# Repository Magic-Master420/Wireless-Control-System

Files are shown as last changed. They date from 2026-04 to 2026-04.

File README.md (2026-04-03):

# Wireless Control System

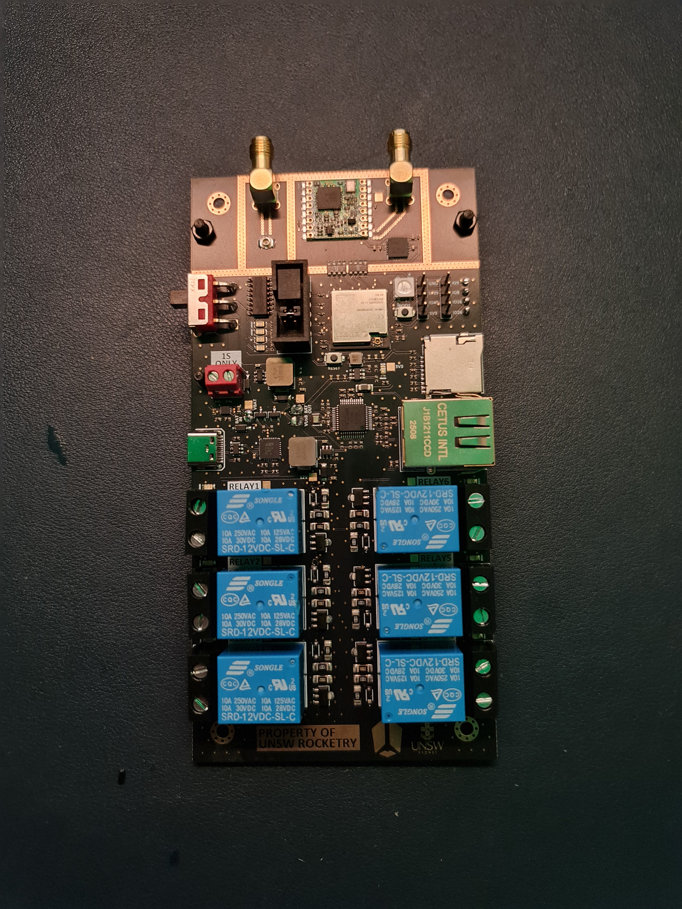
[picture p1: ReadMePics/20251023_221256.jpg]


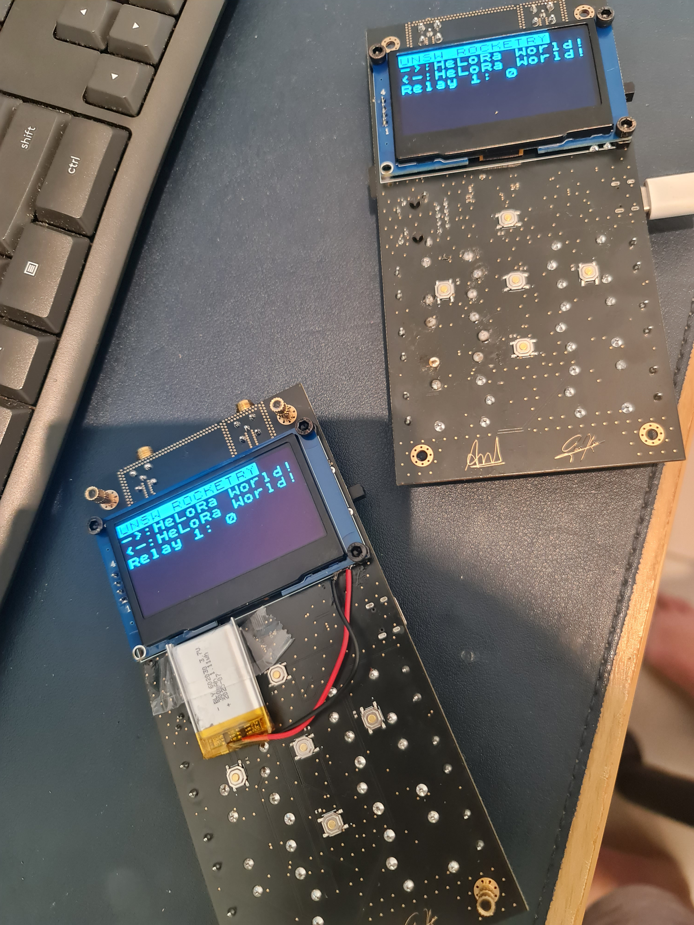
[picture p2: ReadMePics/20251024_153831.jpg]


## Overview
This project was tasked by UNSW rocketry's propulsions sub-team to design a wireless module which is used to launch a two stage rocket over a 800m distance and retrieve sensor data.

The module is powered by an ESP32-S3-MINI-U1 which features a dual core processor, where each processor can be used for a dedicated function. For wireless communication, it is done over LoRa. An off-the-shelf module is utilized in this design. Other features includes an OLED display for viewing information, battery charging system to make the device modular, relays for high voltage/current control, and ethernet for high bandwidth wired communication.

## Known issues
- The wireless charging IC needs two pull up resistors on the battery status indicator pins to correctly display battery state. The pins are open drain which is mentioned in the datasheet but I didn't realize I needed them. Update your schematics accordingly.
- The zener diode implemented on the relay-controls schematic has a breakdown voltage of 4.7V while the anode voltage is 12V and the cathode is about 0V. This caused the supply voltage to constantly be clamped to 4.7V which hinders the functionality of the relays. Remove the zener diode or use a diode with a higher breakdown voltage in your design.

## Notes
- Relays utilized can be connected to mains voltage for high power control. See BOM for part number and search the datasheet for more details on the part.
- The design includes male breakout headers pins for unused pin connections on the ESP32, you can connect external devices to these pins for control. The header pins also include an I2C bus.
- The code is written such that the data is transmitted without checking whether or not it has successfully been received on the other end. The transport layer needs to be improved to ensure reliable communication. Here are some recommended transport layer protocols:
  - Stop-And-Wait:     low throughput, low memory
  - Go-Back-N:         High throughput, low memory
  - Selective-Repeat:  High throughput, high memory

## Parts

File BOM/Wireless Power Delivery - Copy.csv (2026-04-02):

Line # | Name | Description | Designator | Revision ID | Revision Status | Quantity | Manufacturer 1 | Manufacturer Part Number 1 | Manufacturer Lifecycle 1 | Supplier 1 | Supplier Part Number 1 | Supplier Unit Price 1 | Supplier Subtotal 1
 | CL05B104KB54PNC | Capacitor SMD 0402 | C1, C2, C5, C10, C12, C14, C15, C18, C19, C21, C28, C29, C30, C31, C32, C33, C34 |  |  | 17
 | CL05A106MQ5NUNC | Capacitor SMD 0402 | C3, C4, C9, C11, C13, C16, C17, C20, C22, C27, C35 |  |  | 11
 | GRM158R61A226ME15D | Capacitor SMD 0402 | C6, C7, C8, C23, C24, C25, C26 |  |  | 7
 | 0402B223K500NT | Capacitor SMD 0402 | C36 |  |  | 1
 | 0402CG8R0C500NT | Capacitor SMD 0402 | C37, C39 |  |  | 2
 | 0402B682K500NT | Capacitor SMD 0402 | C38, C40 |  |  | 2
 | CL05B103KB5NNNC | Capacitor SMD 0402 | C41, C43 |  |  | 2
 | CL05A475MP5NRNC | Capacitor SMD 0402 | C42 |  |  | 1
 | CC0402KRX7R0BB102 | Capacitor SMD 0402 100V | C44 |  |  | 1
 | TF PUSH |  | CARD1 |  |  | 1
 | USBLC6-2SC6 |  | D1 |  |  | 1
 | 1N5819HW-7-F | DIODE SCHOTTKY 40V 1A SOD123 | D2, D3 | CMP-0303-00003-3 | Up to date | 2 | Diodes Inc. | 1N5819HW-7-F | Volume Production | Avnet | 51R7874 | 0.312 | 0.624
 | LTST-C170KFKT | LED ORANGE CLEAR SMD | D5 | CMP-22017-000036-1 | Up to date | 1 | Lite-On | LTST-C170KFKT | Volume Production | DigiKey | 160-1413-1-ND | 0.13 | 0.13
 | SS34LWHRVG | DIODE SCHOTTKY 40V 3A SOD123W | D6, D9 | CMP-15604-000001-1 | Up to date | 2 | Taiwan Semiconductor | SS34LWHRVG | Volume Production
 | LTST-C170KRKT | LED Red, 75 mW, 54 mcd, -55 to 85 degC, 2-Pin SMD, RoHS, Tape and Reel | DS1, DS2, DS3, DS4, DS5, DS6, DS7, DS8, DS9 | CMP-2000-07593-1 | Up to date | 9 | Lite-On | LTST-C170KRKT | Volume Production | Mouser | 859-LTST-C170KRKT | 0.111 | 1.11
 | LTST-C170KGKT | Ultra Bright AlInGaP Chip LED, 75 mW, -55 to 85 degC, 2-Pin SMD (0805), RoHS, Tape and Reel | DS10 | CMP-2000-06620-1 | Up to date | 1 | Lite-On | LTST-C170KGKT | Volume Production | DigiKey | 160-1414-1-ND | 0.14 | 0.14
 | BLM31PG121SN1L | Chip Ferrite Bead Array, 1206, 120O @ 100MHz, 0.02O, 25%, 3.5A | FB1 | CMP-0686-00732-3 | Up to date | 1 | Murata | BLM31PG121SN1L | Volume Production | DigiKey | 490-1056-1-ND | 0.3 | 0.3
 | BQ25185DLHR | Integrated Circuit | IC1 |  |  | 1
 | TYPE-C-31-M-12 | USB Type C Connector Horizontal SMT | J1 |  |  | 1
 | J1B1211CCD | CONN JACK 1PORT 100 BASE-T PCB | J2 | CMP-240752-000001-1 | Up to date | 1 | WIZnet | J1B1211CCD | Unknown
 | 72454-010VLF | Connector | J3 |  |  | 1
 | U.FL-R-SMT-1(80) | CONN U.FL RCPT STR 50 OHM SMD | J6 | CMP-11598-000004-1 | Up to date | 1 | HIROSE ELECTRIC | U.FL-R-SMT-1(80) | Volume Production | DigiKey | 26-U.FL-R-SMT-1(80)CT-ND | 1.27 | 1.27
 | IHLP1212BZER2R2M11 | FIXED IND 2.2UH 3A 46 MOHM SMD | L1 | CMP-02424-000689-1 | Up to date | 1 | Vishay | IHLP1212BZER2R2M11 | Obsolete
 | IHLP2525EZER4R7M01 | Commercial Inductors, High Saturation Series 4.7uH 6.5A 30.3mO 20% | L2, L3 | CMP-02424-000065-1 | Up to date | 2 | Vishay | IHLP2525EZER4R7M01 | Volume Production | Farnell | IHLP2525EZER4R7M01 | 1.71 | 3.42
 | XL-5050RGBC-WS2812B |  | LED1 |  |  | 1
 | HS242L03B2C01 |  | OLED1 |  |  | 1
 | 61300411121 |  | P2, P3 | CMP-1502-01064-3 | Out of date | 2 | Wurth Elektronik | 61300411121 | Unknown | Mouser | 710-61300411121 | 0.19 | 0.38
 | D882(RANGE:160-320) |  | Q1, Q2, Q3, Q4, Q5, Q6 |  |  | 6
 | L8050QLT1G |  | Q7, Q8 |  |  | 2
 | RC1206FR-7W1KL | Resistor SMD 1206 1k 0.5W | R1, R12, R13, R14, R17, R18, R21, R22, R23, R24, R25, R26 |  |  | 12
 | 0402WGF5101TCE | Resistor SMD 0402 5.1k | R2, R3 |  |  | 2
 | 0402WGF1001TCE | Resistor SMD 0402 | R4, R8, R54, R55, R56, R57 |  |  | 6
 | 0402WGF1002TCE | Resistor SMD 0402 | R5, R7, R9, R16, R31, R33, R34, R35, R36, R37, R38, R39, R40, R41, R42, R44, R45, R46, R47, R48, R60, R61, R66, R67, R68 |  |  | 25
 | 0402WGF3322TCE | Resistor SMD 0402 | R6 |  |  | 1
 | 0402WGF2212TCE | Resistor SMD 0402 | R10 |  |  | 1
 | 0402WGF8202TCE | Resistor SMD 0402 | R11 |  |  | 1
 | 1206W4F1002T5E | Resistor SMD 1206 10k 0.25W | R15, R19, R20, R27, R28, R29 |  |  | 6
 | RC0402FR-074K3L | Resistor SMD 0402 | R30 |  |  | 1
 | RC0402FR-0747K5L | Resistor SMD 0402 | R32 |  |  | 1
 | 0603WAF1302T5E | Resistor SMD 0603 | R43 |  |  | 1
 | 0402WGF3000TCE | Resistor SMD 0402 | R49 |  |  | 1
 | CL0402FN604RP | Resistor SMD 0402 | R50 |  |  | 1
 | 0402WGF1201TCE | Resistor SMD 0402 | R51 |  |  | 1
 | FRC0402F3001TS | Resistor SMD 0402 | R52 |  |  | 1
 | RC0402FR-076K04L | Resistor SMD 0402 | R53 |  |  | 1
 | RC0402FR-07110KL | Resistor SMD 0402 | R58 |  |  | 1
 | 0402WGF1502TCE | Resistor SMD 0402 | R59 |  |  | 1
 | RT0402BRE0750RL | Resistor SMD 0402 | R62, R63, R70, R71 |  |  | 4
 | 0402WGF100JTCE | Resistor SMD 0402 | R64 |  |  | 1
 | 0402WGF1004TCE | Resistor SMD 0402 | R65 |  |  | 1
 | 0402WGF1242TCE | Resistor SMD 0402 | R69 |  |  | 1
 | 0402WGF3300TCE | Resistor SMD 0402 | R72, R73 |  |  | 2
 | 0402WGF330JTCE | Resistor SMD 0402 | R74, R75, R76, R77 |  |  | 4
 | SRD-12VDC-SL-C |  | RELAY1, RELAY2, RELAY3, RELAY4, RELAY5, RELAY6 |  |  | 6
 | BWSMA-KWE-Z001 |  | RF1, RF2 |  |  | 2
 | YC324-JK-070RL | Resistor Network | RN1, RN2 |  |  | 2
 | TS-1187A-B-A-B | Switch | S1, S2, S3, S4, S5 |  |  | 5
 | SS-12D11G5R | Switch | S6 |  |  | 1
 | SolderBridgeOpen | Close the brige with solder | SB1, SB2, SB3 |  |  | 3
 | TS-1088-AR02016 |  | SW1, SW2 |  |  | 2
 | ESP32-S3-MINI-1U-N8 | Bluetooth, WiFi 802.11b/g/n, Bluetooth v5.0 Transceiver Module 2.4GHz Antenna Not Included, U.FL Surface Mount | U1 |  |  | 1
 | TPS563200DDCR | IC REG BUCK ADJ 3A TSOT23-6 | U2 | CMP-04918-000155-1 | Up to date | 1 | Texas Instruments | TPS563200DDCR | Volume Production | Mouser | 595-TPS563200DDCR | 1.02 | 1.02
 | CP2102N-A02-GQFN28R | IC USB TO UART BRIDGE QFN28 | U3 | CMP-08093-000007-1 | Up to date | 1 | Silicon Lab | CP2102N-A02-GQFN28R | Volume Production | Mouser | 634-CP2102NA02QFN28R | 3.52 | 3.52
 | XY705V-7.5-2P |  | U4, U5, U6, U7, U8, U9 |  |  | 6
 | DB125-3.81-2P-RD-S |  | U10 |  |  | 1
 | MT3608L |  | U11, U15 |  |  | 2
 | TPS7A4700RGWR | IC REG LINEAR POS ADJ 1A 20VQFN | U12 | CMP-04917-000027-1 | Up to date | 1 | Texas Instruments | TPS7A4700RGWR | Volume Production
 | 915MHz |  | U13 |  |  | 1
 | SN74HC139DR | Dual 2-Line To 4-Line Decoders/Demultiplexers, D0016A, LARGE T&R | U14 | CMP-1633-00245-2 | Up to date | 1 | Texas Instruments | SN74HC139DR | Volume Production | Mouser | 595-SN74HC139DR | 0.46 | 0.46
 | W5500 | Hardwired TCP/IP embedded Ethernet controller | U16 |  |  | 1
 | XRCGB25M000F3A00R0 | CRYSTAL 25.0000MHZ 6PF SMD | Y1 | CMP-06054-000016-1 | Up to date | 1 | Murata | XRCGB25M000F3A00R0 | Volume Production | Newark | XRCGB25M000F3A00R0 | 0.509 | 0.509
 | BZT52C4V7 | Zener Diode | Z1, Z2, Z3, Z4, Z5, Z6 |  |  | 6

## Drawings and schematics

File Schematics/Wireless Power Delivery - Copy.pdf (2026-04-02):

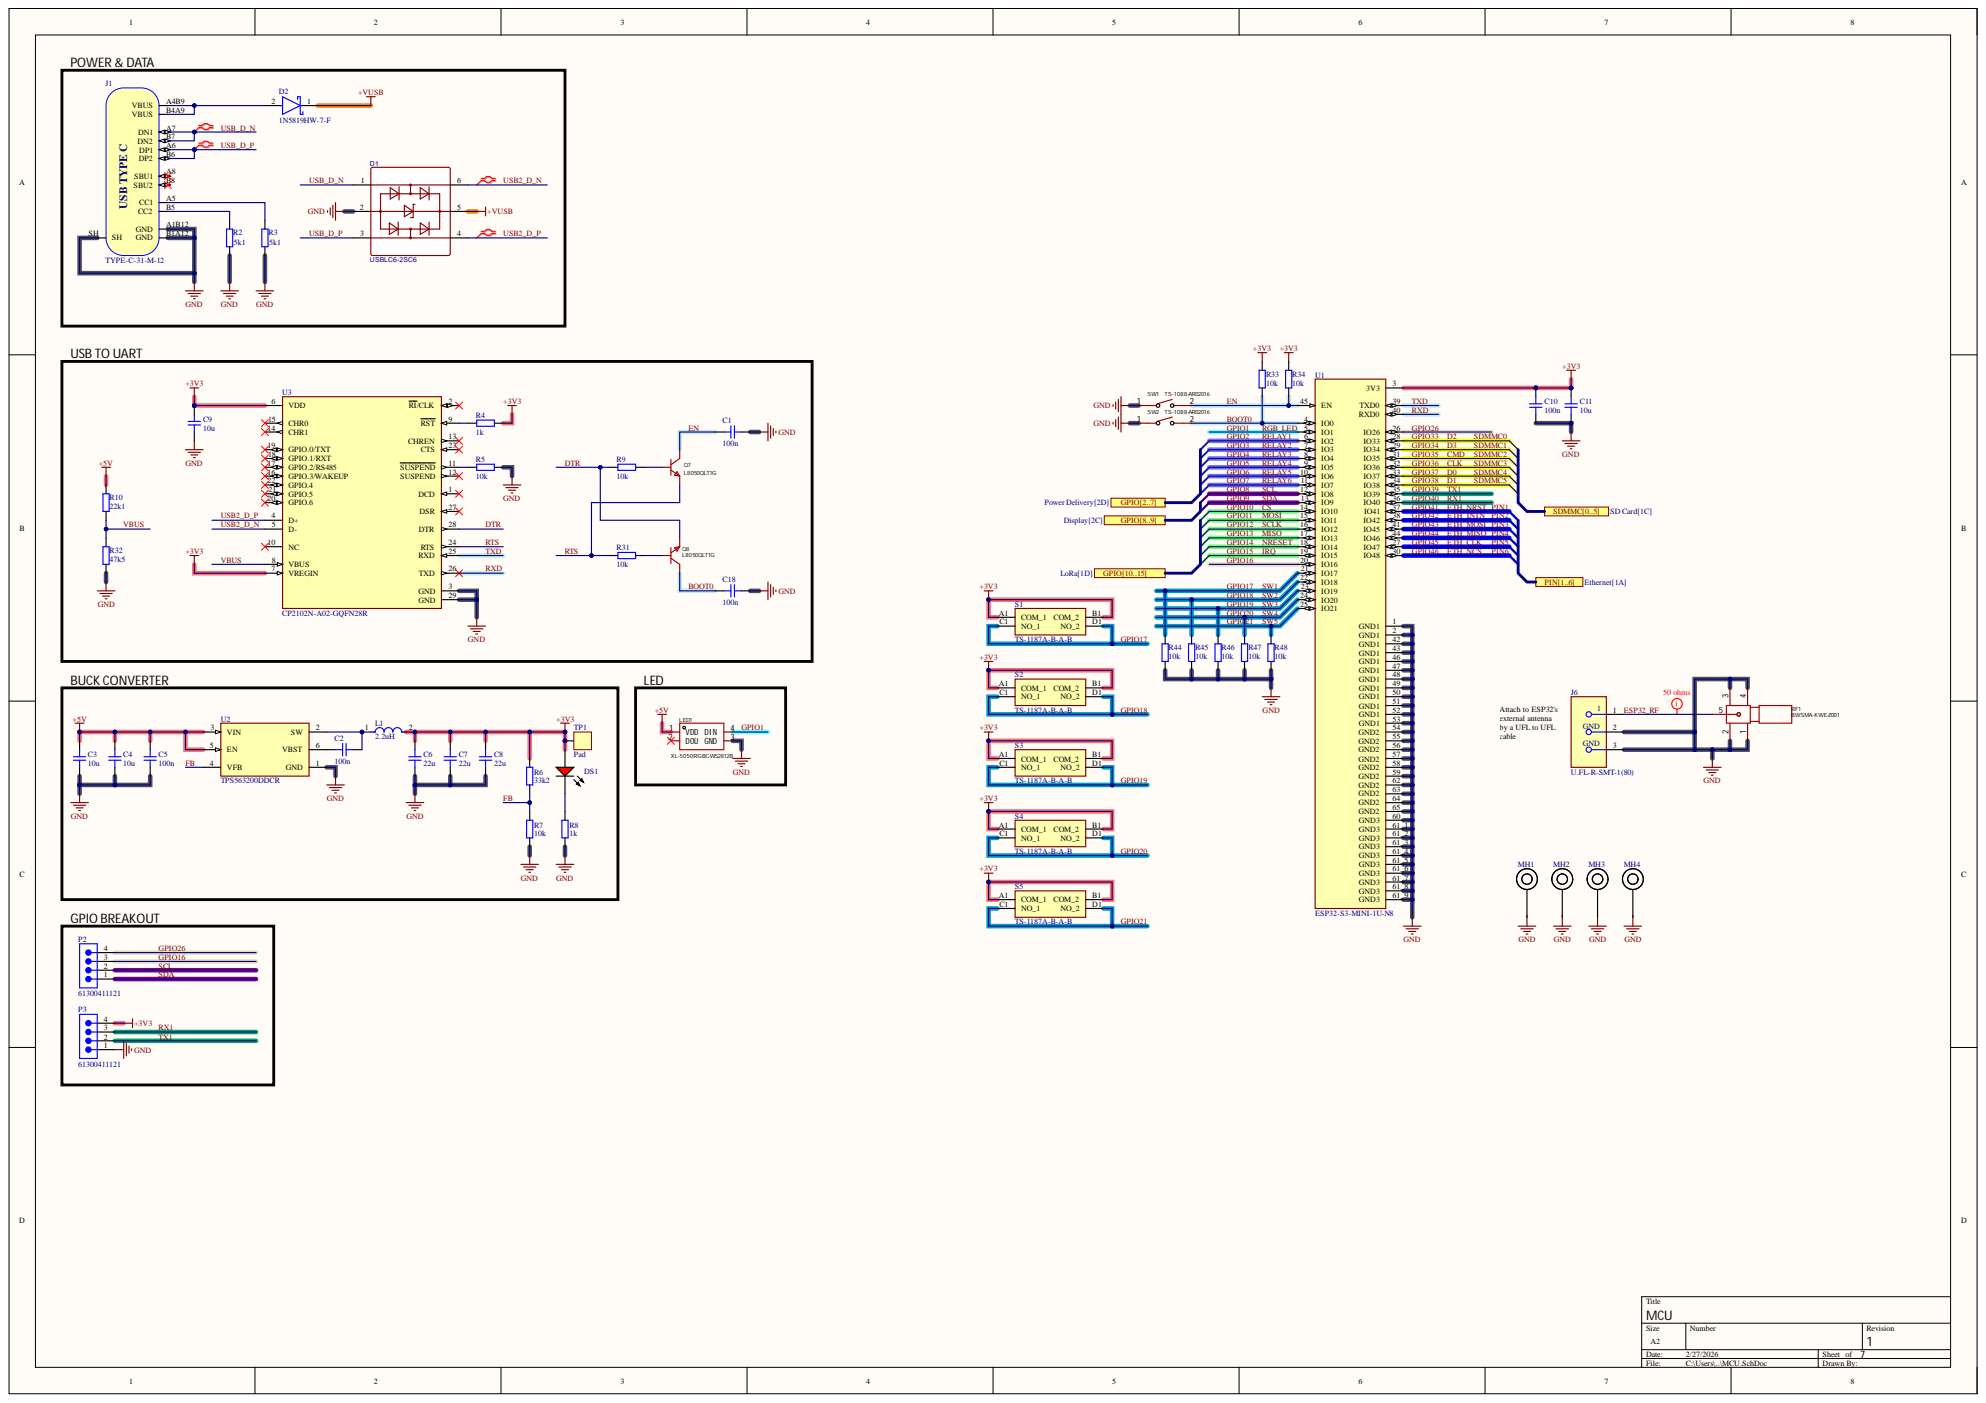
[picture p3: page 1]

Attach to ESP32's
external antenna
by a UFL to UFL
cable

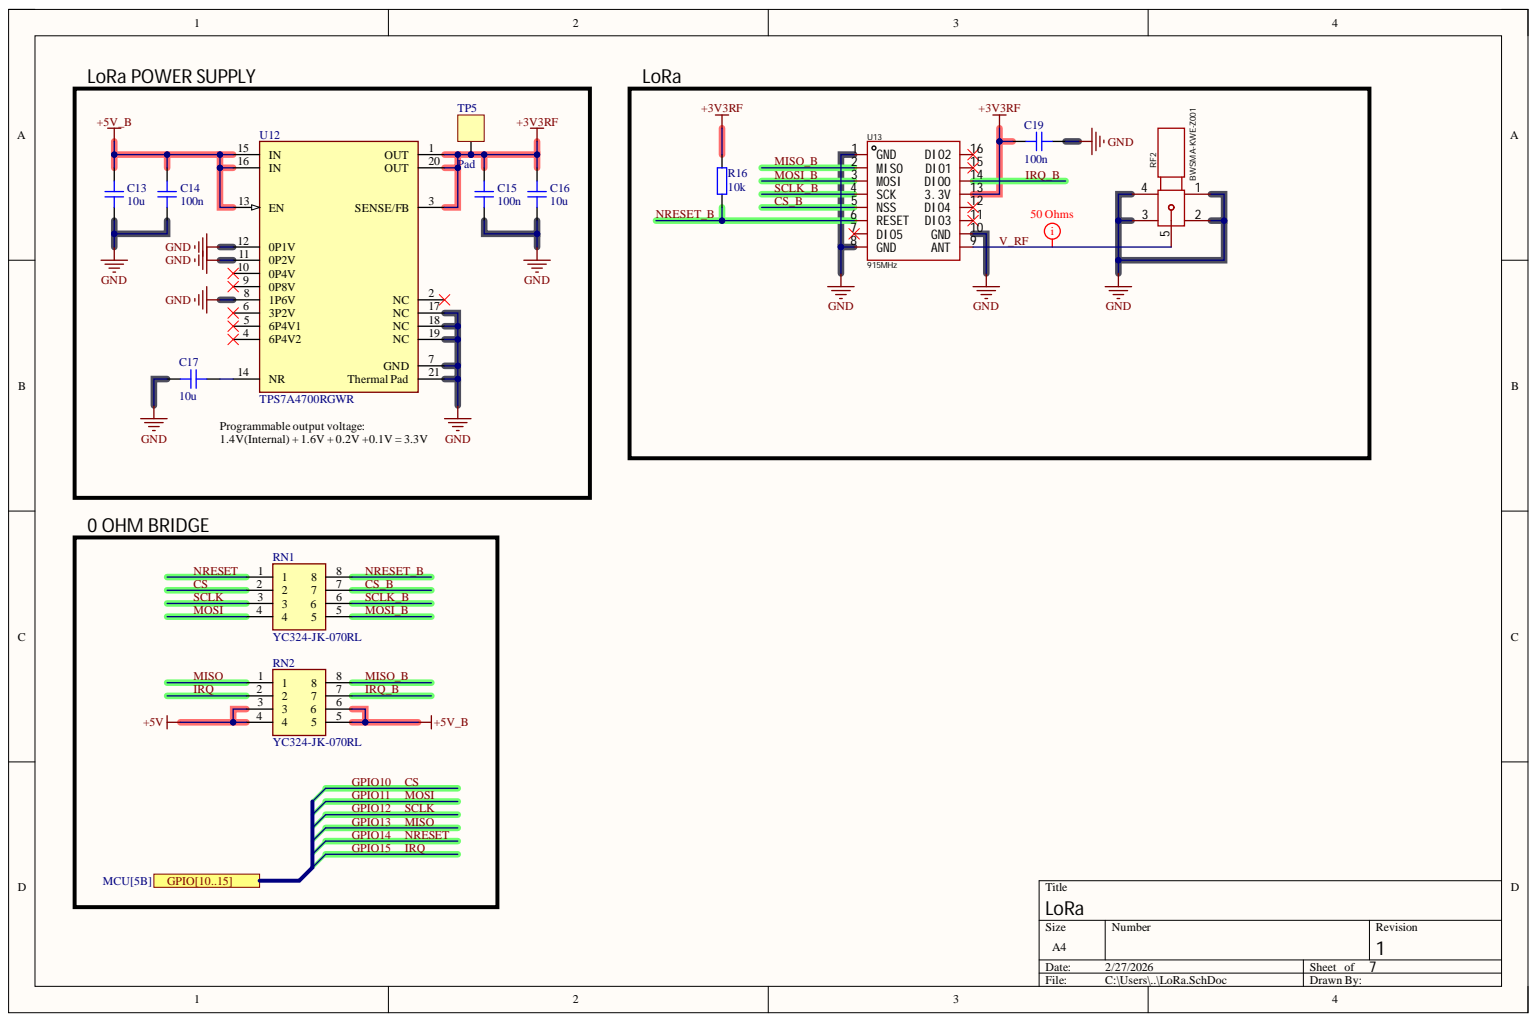
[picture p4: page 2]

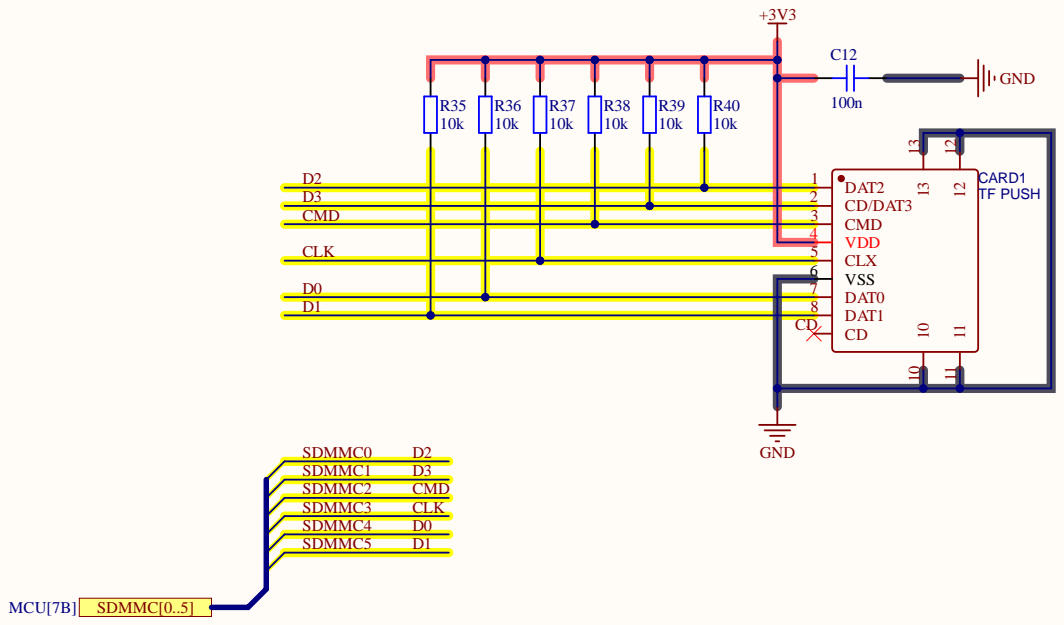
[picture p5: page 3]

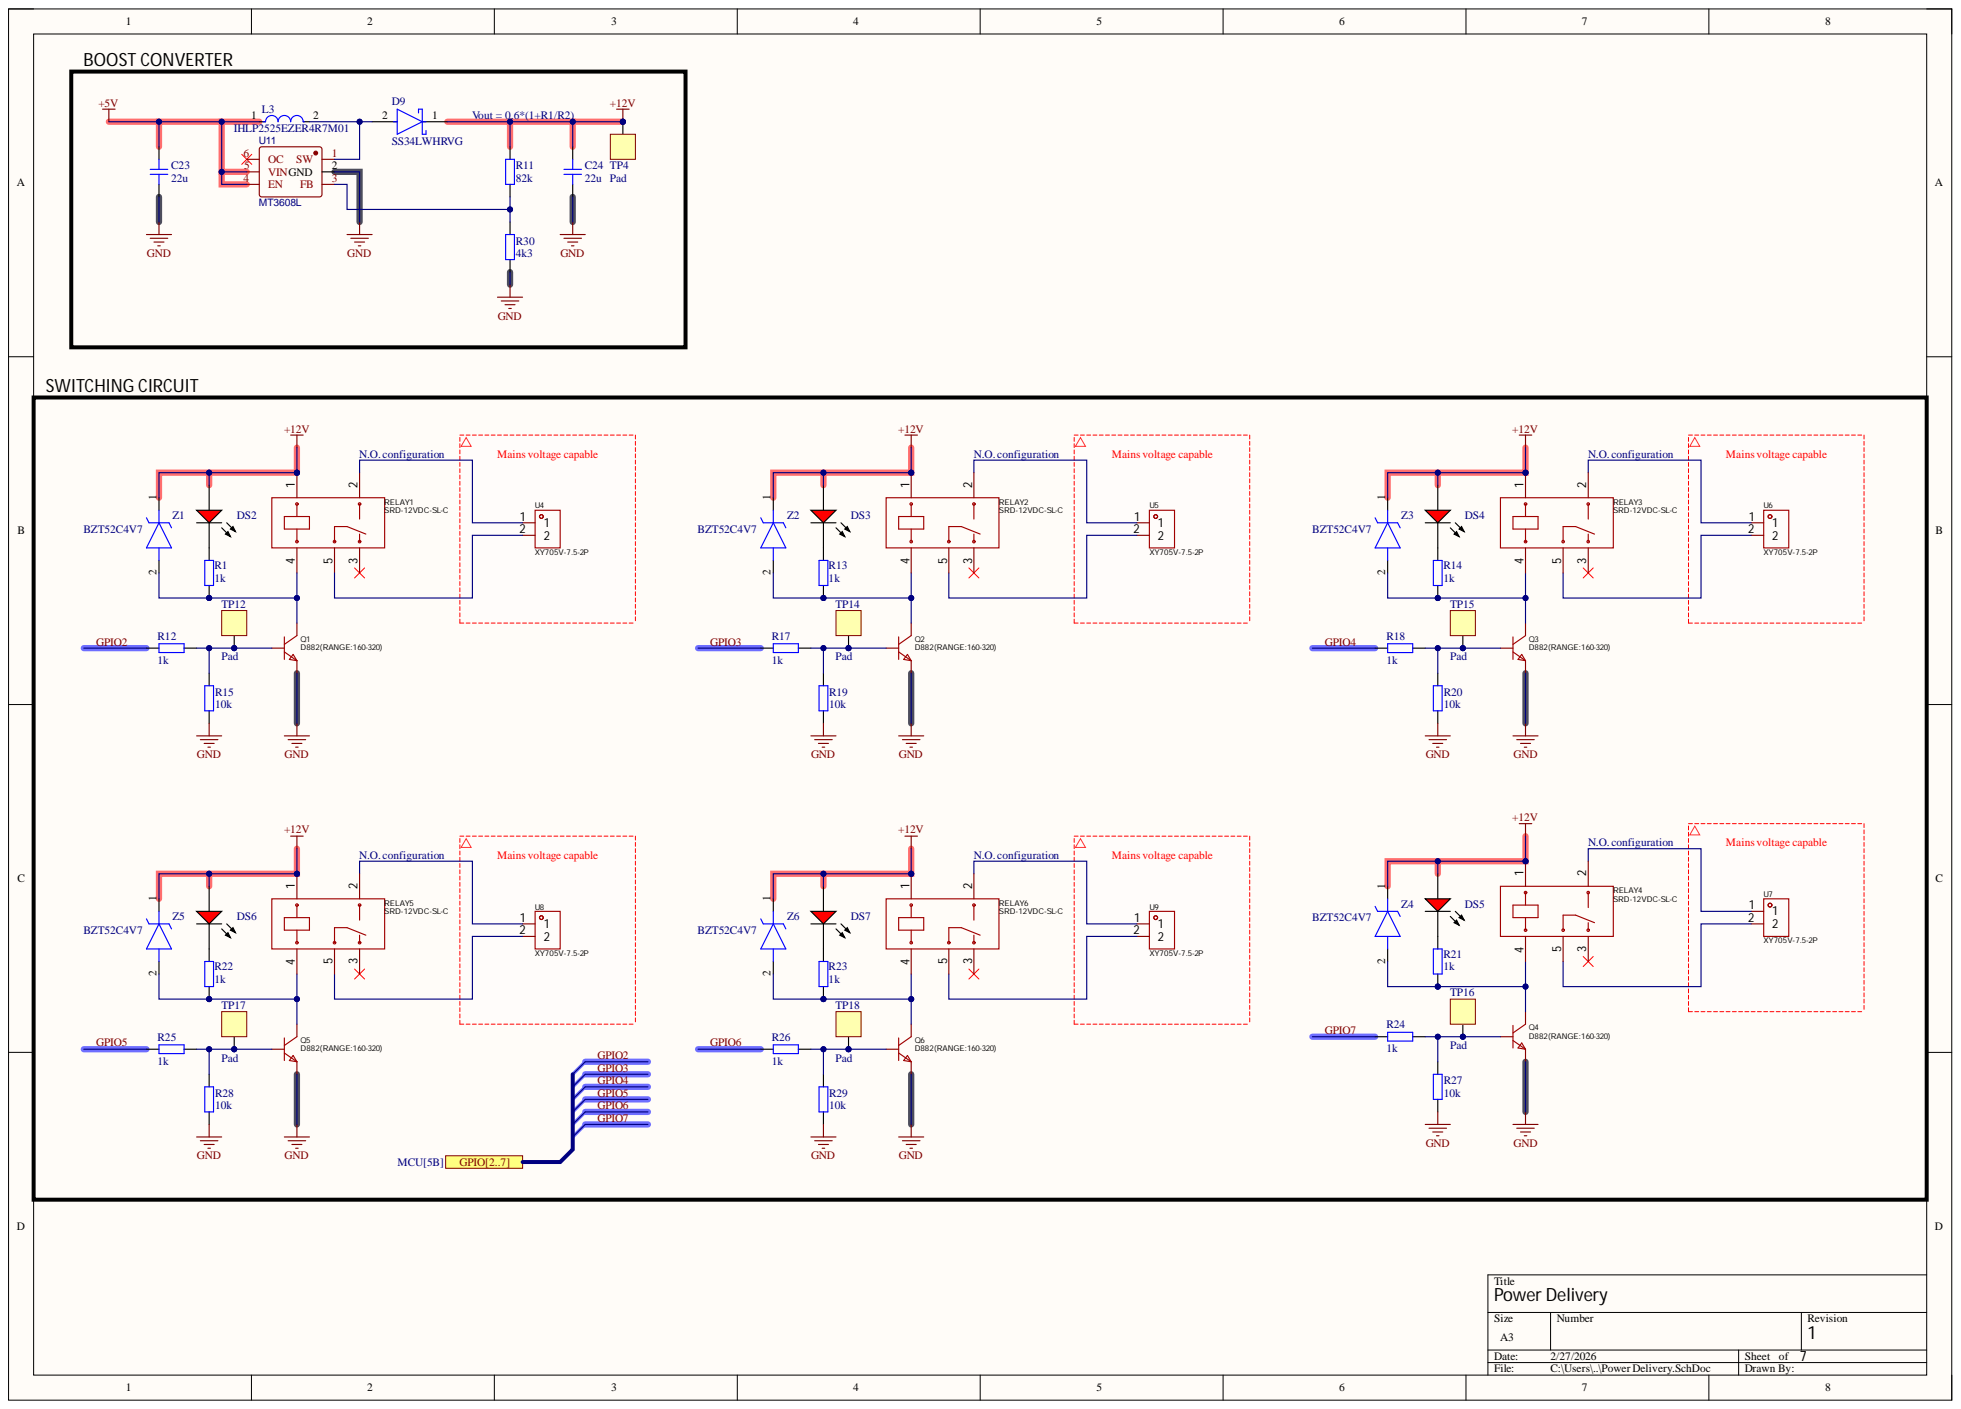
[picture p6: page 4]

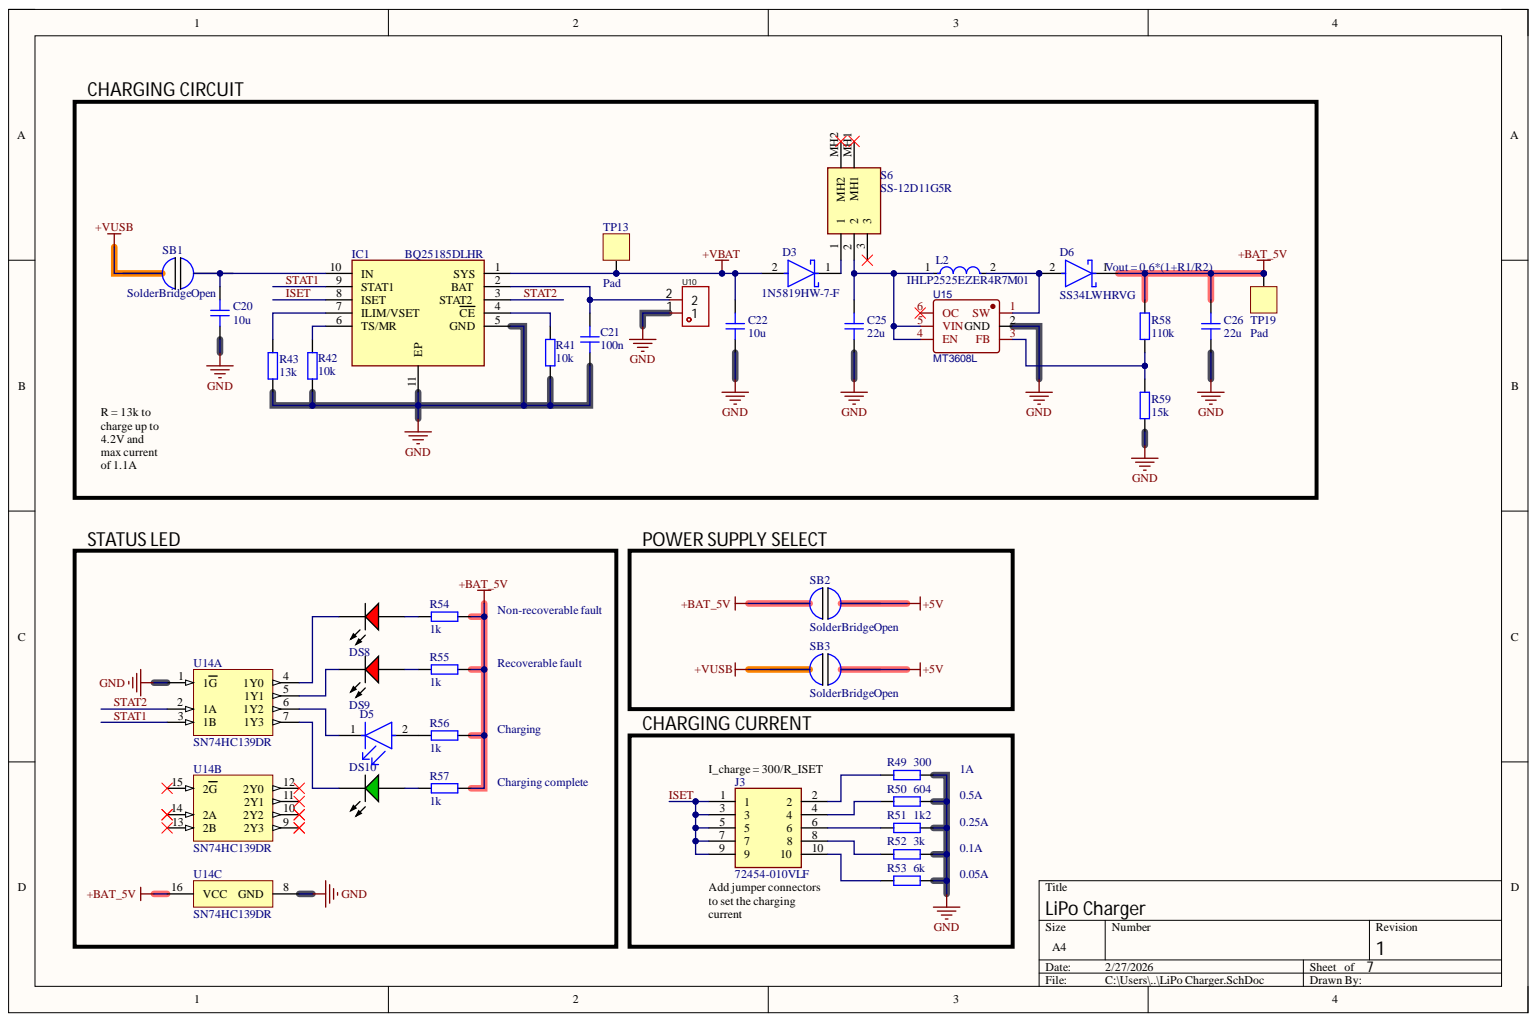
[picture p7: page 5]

72454-010VLF
Add jumper connectors
to set the charging
current

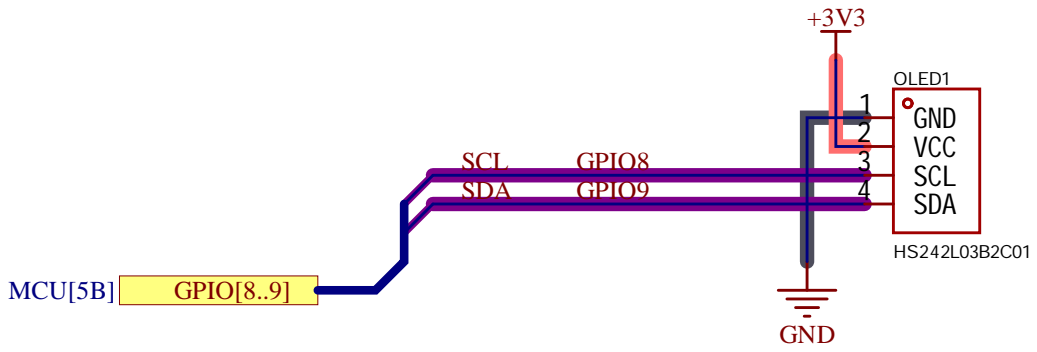
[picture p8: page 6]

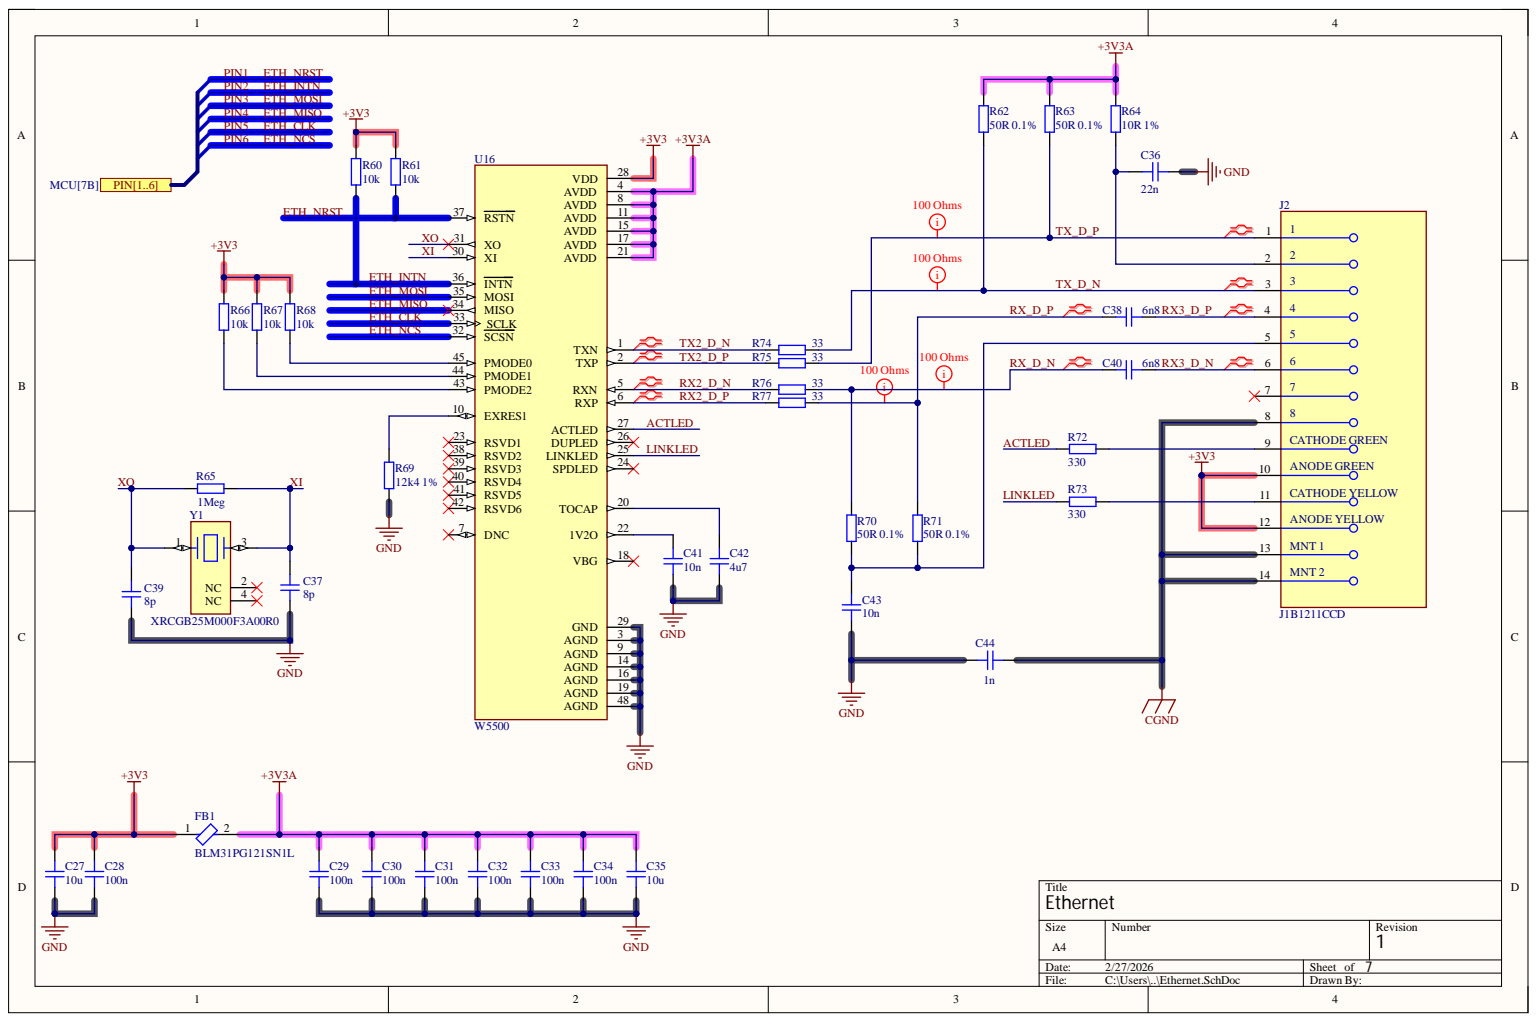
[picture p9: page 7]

100 Ohms | RX_D_N

EXRES1 10

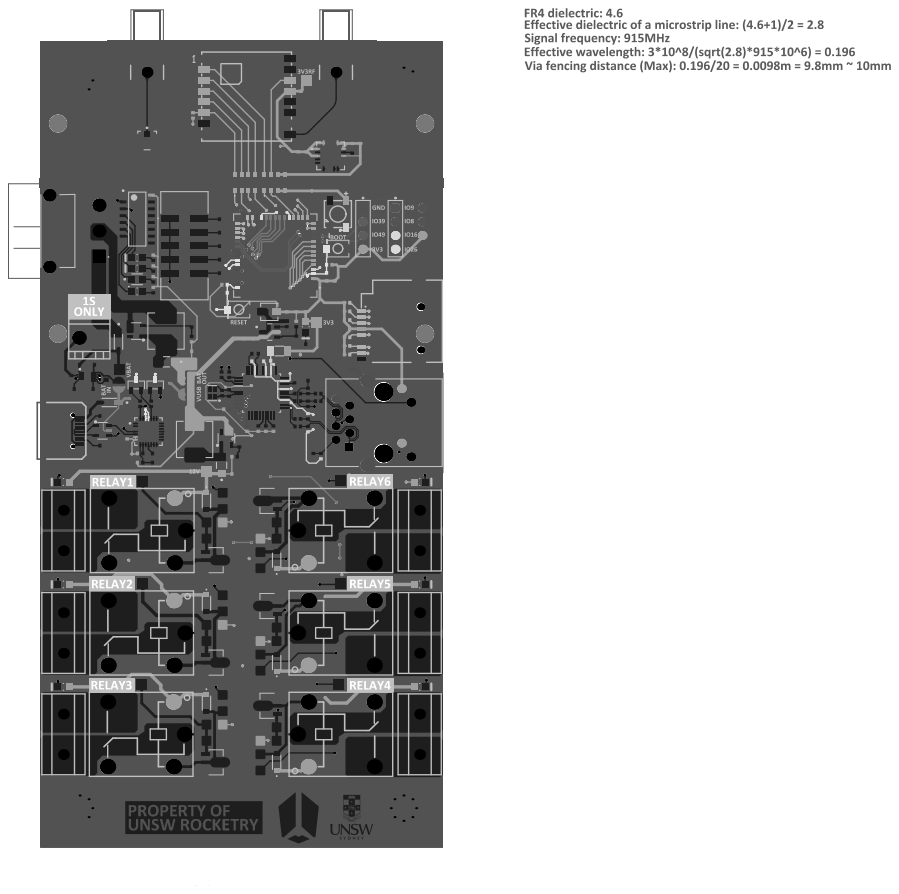
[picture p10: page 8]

Line# | Name | Description | Designator | Revision ID | Revision Status | Quantity | Manufacturer 1 | Manufacturer Part Number 1 | Manufacturer Lifecycle1 | Supplier 1 | Supplier Part Number 1 | Supplier Unit Price1 | Supplier Subtotal 1
CL05B104KB54PNC | Capacitor SMD

C1, C2, C5, C10,
C12, C14, C15,
C18, C19, C21,
C28, C29, C30,
C31, C32, C33, C34
CL05A106MQ5NUNC | Capacitor SMD | C3, C4, C9, C11, C13, C16, C17, C20, C22, C27, C35
GRM158R61A226ME15D | Capacitor SMD 0402 | C6, C7, C8, C23, C24, C25, C26 | | 7
0402B223K500NT | Capacitor SMD 0402 | C36 | | 1
0402CG8R0C500NT | Capacitor SMD 0402 | C37, C39 | | 2
0402B682K500NT | Capacitor SMD 0402 | C38, C40 | | 2
CL05B103KB5NNNC | Capacitor SMD 0402 | C41, C43 | | 2
CL05A475MP5NRNC | Capacitor SMD 0402 | C42 | | 1
CC0402KRX7R0BB102 | Capacitor SMD 0402100V | C44 | | 1
TFPUSH | | CARD1 | | 1
USBLC6-2SC6 | | D1 | | 1
1N5819HW-7-F | DIODESCHOTTKY 40V1ASOD123 | D2, D3 | | 2 Diodes Inc. | 1N5819HW-7-F | VolumeProduction
LTST-C170KFKT | LEDORANGE CLEARSMD | D5 | | 1 Lite-On | LTST-C170KFKT | VolumeProduction
SS34LWHRVG | DIODESCHOTTKY 40V3ASOD123W | D6, D9 | | 2 Taiwan Semiconductor | SS34LWHRVG | VolumeProduction
LTST-C170KRKT | LEDRed, 75mW, 54mcd, -55to 85 degC, 2-Pin SMD, RoHS, Tapeand Reel | DS1, DS2, DS3, DS4, DS5, DS6, DS7, DS8, DS9 | | 9 Lite-On | LTST-C170KRKT | VolumeProduction
LTST-C170KGKT | Ultra Bright AlInGaPChip LED, 75mW, -55to 85 degC, 2-Pin SMD (0805), RoHS, Tapeand Reel | DS10 | | 1 Lite-On | LTST-C170KGKT | VolumeProduction
BLM31PG121SN1L | Chip FerriteBead Array, 1206, 120Ω @100MHz, 0.02Ω, 25%, 3.5A | FB1 | | 1 Murata | BLM31PG121SN1L | VolumeProduction
BQ25185DLHR | Integrated Circuit | IC1 | | 1
TYPE-C-31-M-12 | USBTypeC Connector Horizontal SMT | J1 | | 1
J1B1211CCD | CONN JACK 1PORT100BASE-T PCB | J2 | | 1 WIZnet | J1B1211CCD
72454-010VLF | Connector | J3 | | 1
U.FL-R-SMT-1(80) | CONN U.FLRCPT STR50OHMSMD | J6 | | 1 HIROSEELECTRIC | U.FL-R-SMT-1(80) | VolumeProduction
IHLP1212BZER2R2M11 | FIXEDIND2.2UH 3A46MOHMSMD | L1 | | 1 Vishay | IHLP1212BZER2R2M11 | Obsolete
IHLP2525EZER4R7M01 | Commercial Inductors, High Saturation Series 4.7uH6.5A 30.3mΩ20% | L2, L3 | | 2 Vishay | IHLP2525EZER4R7M01 | VolumeProduction
XL-5050RGBC-WS2812B | | LED1 | | 1
HS242L03B2C01 | | OLED1 | | 1
61300411121 | | P2, P3 | | 2 Wurth Elektronik | 61300411121
D882(RANGE:160-320) | | Q1, Q2, Q3, Q4, Q5, Q6 | | 6
L8050QLT1G | | Q7, Q8 | | 2
RC1206FR-7W1KL | Resistor SMD1206 1k 0.5W | R1, R12, R13, R14, R17, R18, R21, R22, R23, R24, R25, R26 | 12
0402WGF5101TCE | Resistor SMD0402 5.1k | R2, R3 | | 2
0402WGF1001TCE | Resistor SMD0402 R4, R8, R54, R55, | R56, R57 | | 6
0402WGF1002TCE | Resistor SMD0402 | R5, R7, R9, R16, R31, R33, R34, R35, R36, R37, R38, R39, R40, R41, R42, R44, R45, R46, R47, R48, R60, R61, R66, R67, R68 | 25
0402WGF3322TCE | Resistor SMD0402 R6 | | | 1
0402WGF2212TCE | Resistor SMD0402 R10 | | | 1
0402WGF8202TCE | Resistor SMD0402 R11 | | | 1
1206W4F1002T5E | Resistor SMD1206 10k 0.25W | R15, R19, R20, R27, R28, R29 | | 6
RC0402FR-074K3L | Resistor SMD0402 R30 | | | 1
RC0402FR-0747K5L | Resistor SMD0402 R32 | | | 1
0603WAF1302T5E | Resistor SMD0603 R43 | | | 1
0402WGF3000TCE | Resistor SMD0402 R49 | | | 1
CL0402FN604RP | Resistor SMD0402 R50 | | | 1
0402WGF1201TCE | Resistor SMD0402 R51 | | | 1
FRC0402F3001TS | Resistor SMD0402 R52 | | | 1
RC0402FR-076K04L | Resistor SMD0402 R53 | | | 1
RC0402FR-07110KL | Resistor SMD0402 R58 | | | 1
0402WGF1502TCE | Resistor SMD0402 R59 | | | 1
RT0402BRE0750RL | Resistor SMD0402 R62, R63, R70, R71 | | | 4
0402WGF100JTCE | Resistor SMD0402 R64 | | | 1
0402WGF1004TCE | Resistor SMD0402 R65 | | | 1
0402WGF1242TCE | Resistor SMD0402 R69 | | | 1
0402WGF3300TCE | Resistor SMD0402 R72, R73 | | | 2
0402WGF330JTCE | Resistor SMD0402 R74, R75, R76, R77 | | | 4
SRD-12VDC-SL-C | | RELAY1, RELAY2, RELAY3, RELAY4, RELAY5, RELAY6 | | 6
BWSMA-KWE-Z001 | | RF1, RF2 | | 2
YC324-JK-070RL | Resistor Network | RN1, RN2 | | 2
TS-1187A-B-A-B | Switch | S1, S2, S3, S4, S5 | | 5
SS-12D11G5R | Switch | S6 | | 1
SolderBridgeOpen | Closethebrige with solder | SB1, SB2, SB3 | | 3
TS-1088-AR02016 | | SW1, SW2 | | 2
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

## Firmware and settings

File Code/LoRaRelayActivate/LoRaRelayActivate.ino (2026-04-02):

/*
  LoRa Duplex communication wth callback

  Sends a message every half second, and uses callback
  for new incoming messages. Implements a one-byte addressing scheme,
  with 0xFF as the broadcast address.

  Note: while sending, LoRa radio is not listening for incoming messages.
  Note2: when using the callback method, you can't use any of the Stream
  functions that rely on the timeout, such as readString, parseInt(), etc.

  created 28 April 2017
  by Tom Igoe
*/
#include <SPI.h>              // include libraries
#include <LoRa.h>
#include <Arduino.h>
#include <U8x8lib.h>
#include <Wire.h>

#ifdef U8X8_HAVE_HW_SPI
#endif

#ifdef ARDUINO_SAMD_MKRWAN1300
#error "This example is not compatible with the Arduino MKR WAN 1300 board!"
#endif

const int csPin = 10;          // LoRa radio chip select
const int resetPin = 14;       // LoRa radio reset
const int irqPin = 15;         // change for your board; must be a hardware interrupt pin
int pushButtonMiddlePin = 17;
volatile bool isPushButtonPressed = false;
int relay1Pin = 2;
int relay1State = 0;
int lastInterruptTime = 0;
char timeString[16];

String message = "HeLoRa World!";   // send a message
String recievedMessage = "";
String toggleRelayMiddle = "Toggle relay";
String sendMyMessage = "";

String outgoing;              // outgoing message
byte msgCount = 0;            // count of outgoing messages
byte localAddress = 0xBB;     // address of this device
byte destination = 0xFF;      // destination to send to
int lastSendTime = 0;        // last send time
int lastRecievedTime = 0;    // last recieved time
int interval = 2000;          // interval between sends

U8X8_SSD1306_128X64_NONAME_HW_I2C u8x8(U8X8_PIN_NONE);

void setup() {
  Serial.begin(115200);                   // initialize serial

  while (!Serial);

  // ********** LoRa setup **********
  Serial.println("LoRa Duplex with callback");
  //SPI.begin(SCK, MISO, MOSI, SS);
  SPI.begin(12, 13, 11, 10);  
  // override the default CS, reset, and IRQ pins (optional)
  LoRa.setPins(csPin, resetPin, irqPin);// set CS, reset, IRQ pin
  if (!LoRa.begin(915E6)) {             // initialize ratio at 915 MHz
    Serial.println("LoRa init failed. Check your connections.");
    while (true);                       // if failed, do nothing
  }
  LoRa.onReceive(onReceive);
  LoRa.receive();
  Serial.println("LoRa init succeeded.");
  // ********** LoRa setup **********
  
  // ********** Button and relay setup **********
  attachInterrupt(digitalPinToInterrupt(pushButtonMiddlePin), pushButtonISR, RISING);
  pinMode(relay1Pin, OUTPUT);
  digitalWrite(relay1Pin, LOW);
  // ********** Button and relay setup **********

  // ********** Display setup **********
  Wire.begin(9, 8);    // Set custom SDA and SCL pins
  u8x8.begin();
  u8x8.setPowerSave(0);
  u8x8.setFont(u8x8_font_chroma48medium8_r);
  u8x8.setInverseFont(1);
  u8x8.drawString(0,0," UNSW ROCKETRY ");
  u8x8.setInverseFont(0);
  // ********** Display setup **********
}

void loop() {
  if (millis() - lastSendTime > interval) {
    if(isPushButtonPressed){
      sendMessage(toggleRelayMiddle);
      Serial.println("->:" + toggleRelayMiddle);
      sendMyMessage = "->:" + toggleRelayMiddle;
      u8x8.drawString(0,1,"->:             ");
      u8x8.drawString(0,1,sendMyMessage.c_str());
      isPushButtonPressed = false;
    } else{
      sendMessage(message);
      Serial.println("->:" + message);
      sendMyMessage = "->:" + message;
      u8x8.drawString(0,1,"->:             ");
      u8x8.drawString(0,1,sendMyMessage.c_str());
    }
    
    sprintf(timeString, "%d", (millis() - lastSendTime));
    sendMyMessage = "Last sent:" + String(timeString);
    u8x8.drawString(0,2,"Last sent:      ");
    u8x8.drawString(0,2,sendMyMessage.c_str());
    lastSendTime = millis();            // timestamp the message
    interval = 250;//random(2000) + 1000;     // 2-3 seconds
    LoRa.receive();                     // go back into receive mode
    if(recievedMessage == toggleRelayMiddle){
      (relay1State == 1) ? relay1State = 0 : relay1State = 1;
      digitalWrite(relay1Pin, relay1State);
      message = "HeLoRa World!"; // reset back to HeLoRa World to prevent constant change
    }
  }

  sendMyMessage = "<-:" + recievedMessage;
  u8x8.drawString(0,3,"<-:             ");
  u8x8.drawString(0,3,sendMyMessage.c_str());
  sprintf(timeString, "%d", (millis() - lastRecievedTime));
  sendMyMessage = "Last rcvd:" + String(timeString);
  u8x8.drawString(0,4,"Last rcvd:      ");
  u8x8.drawString(0,4,sendMyMessage.c_str());

  sendMyMessage = "Relay 1: " + String(relay1State);
  u8x8.drawString(0,5,"Relay 1:        ");
  u8x8.drawString(0,5,sendMyMessage.c_str());
}

void pushButtonISR(){
  unsigned long currentTime = millis();
  if (currentTime - lastInterruptTime > 200) { // 200 ms debounce
    isPushButtonPressed = true;
    lastInterruptTime = currentTime;
  }
}

void sendMessage(String outgoing) {
  LoRa.beginPacket();                   // start packet
  LoRa.write(destination);              // add destination address
  LoRa.write(localAddress);             // add sender address
  LoRa.write(msgCount);                 // add message ID
  LoRa.write(outgoing.length());        // add payload length   
  LoRa.print(outgoing);                 // add payload
  LoRa.endPacket();                     // finish packet and send it
  msgCount++;                           // increment message ID
}

void onReceive(int packetSize) {
  if (packetSize == 0){
    u8x8.drawString(0,1,"Scanning...");
    return;          // if there's no packet, return
  }


  // read packet header bytes:
  int recipient = LoRa.read();          // recipient address
  byte sender = LoRa.read();            // sender address
  byte incomingMsgId = LoRa.read();     // incoming msg ID
  byte incomingLength = LoRa.read();    // incoming msg length

  String incoming = "";                 // payload of packet

  while (LoRa.available()) {            // can't use readString() in callback, so
    incoming += (char)LoRa.read();      // add bytes one by one
  }

  if (incomingLength != incoming.length()) {   // check length for error
    Serial.println("error: message length does not match length");
    return;                             // skip rest of function
  }

  // if the recipient isn't this device or broadcast,
  if (recipient != localAddress && recipient != 0xFF) {
    Serial.println("This message is not for me.");
    return;                             // skip rest of function
  }

  recievedMessage = incoming;
  // if message is for this device, or broadcast, print details:
  Serial.println("Received from: 0x" + String(sender, HEX));
  Serial.println("Sent to: 0x" + String(recipient, HEX));
  Serial.println("Message ID: " + String(incomingMsgId));
  Serial.println("Message length: " + String(incomingLength));
  Serial.println("Message: " + incoming);
  Serial.println("RSSI: " + String(LoRa.packetRssi()));
  Serial.println("Snr: " + String(LoRa.packetSnr()));
  Serial.println();
  lastRecievedTime = millis();
}

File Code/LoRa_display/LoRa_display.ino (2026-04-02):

/*

  HelloWorld.ino
  
  "Hello World" version for U8x8 API

  Universal 8bit Graphics Library (https://github.com/olikraus/u8g2/)

  Copyright (c) 2016, olikraus@gmail.com
  All rights reserved.

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
  THIS SOFTWARE IS PROVIDED BY THE COPYRIGHT HOLDERS AND 
  CONTRIBUTORS "AS IS" AND ANY EXPRESS OR IMPLIED WARRANTIES, 
  INCLUDING, BUT NOT LIMITED TO, THE IMPLIED WARRANTIES OF 
  MERCHANTABILITY AND FITNESS FOR A PARTICULAR PURPOSE ARE 
  DISCLAIMED. IN NO EVENT SHALL THE COPYRIGHT HOLDER OR 
  CONTRIBUTORS BE LIABLE FOR ANY DIRECT, INDIRECT, INCIDENTAL, 
  SPECIAL, EXEMPLARY, OR CONSEQUENTIAL DAMAGES (INCLUDING, BUT 
  NOT LIMITED TO, PROCUREMENT OF SUBSTITUTE GOODS OR SERVICES; 
  LOSS OF USE, DATA, OR PROFITS; OR BUSINESS INTERRUPTION) HOWEVER 
  CAUSED AND ON ANY THEORY OF LIABILITY, WHETHER IN CONTRACT, 
  STRICT LIABILITY, OR TORT (INCLUDING NEGLIGENCE OR OTHERWISE) 
  ARISING IN ANY WAY OUT OF THE USE OF THIS SOFTWARE, EVEN IF 
  ADVISED OF THE POSSIBILITY OF SUCH DAMAGE.  

*/

#include <Arduino.h>
#include <U8x8lib.h>
#include <Wire.h>

#ifdef U8X8_HAVE_HW_SPI
#include <SPI.h>
#endif

// Please UNCOMMENT one of the contructor lines below
// U8x8 Contructor List 
// The complete list is available here: https://github.com/olikraus/u8g2/wiki/u8x8setupcpp
// Please update the pin numbers according to your setup. Use U8X8_PIN_NONE if the reset pin is not connected
//U8X8_NULL u8x8;	// null device, a 8x8 pixel display which does nothing
//U8X8_SSD1306_128X64_NONAME_4W_SW_SPI u8x8(/* clock=*/ 13, /* data=*/ 11, /* cs=*/ 10, /* dc=*/ 9, /* reset=*/ 8);
//U8X8_SSD1306_128X64_NONAME_4W_HW_SPI u8x8(/* cs=*/ 6, /* dc=*/ 4, /* reset=*/ 12);	// Arduboy (DevKit)
//U8X8_SSD1306_128X64_NONAME_4W_HW_SPI u8x8(/* cs=*/ 12, /* dc=*/ 4, /* reset=*/ 6);	// Arduboy 10 (Production, Kickstarter Edition)
//U8X8_SSD1306_128X64_NONAME_4W_HW_SPI u8x8(/* cs=*/ 10, /* dc=*/ 9, /* reset=*/ 8);
//U8X8_SSD1306_128X64_NONAME_3W_SW_SPI u8x8(/* clock=*/ 13, /* data=*/ 11, /* cs=*/ 10, /* reset=*/ 8);
//U8X8_SSD1306_128X64_NONAME_3W_HW_SPI u8x8(/* cs=*/ 10, /* reset=*/ 8);
//U8X8_SSD1306_128X64_NONAME_HW_I2C u8x8(/* reset=*/ U8X8_PIN_NONE); 	      
//U8X8_SSD1306_128X64_ALT0_HW_I2C u8x8(/* reset=*/ U8X8_PIN_NONE); 	      // same as the NONAME variant, but may solve the "every 2nd line skipped" problem
//U8X8_SSD1306_128X64_NONAME_SW_I2C u8x8(/* clock=*/ 2, /* data=*/ 0, /* reset=*/ U8X8_PIN_NONE); 	      // Digispark ATTiny85
//U8X8_SSD1306_128X64_NONAME_SW_I2C u8x8(/* clock=*/ SCL, /* data=*/ SDA, /* reset=*/ U8X8_PIN_NONE);   // OLEDs without Reset of the Display
//U8X8_SSD1306_128X64_VCOMH0_4W_HW_SPI u8x8(/* cs=*/ 10, /* dc=*/ 9, /* reset=*/ 8);		// same as the NONAME variant, but maximizes setContrast() range
//U8X8_SSD1306_128X64_ALT0_4W_HW_SPI u8x8(/* cs=*/ 10, /* dc=*/ 9, /* reset=*/ 8);		// same as the NONAME variant, but may solve the "every 2nd line skipped" problem
//U8X8_SSD1306_102X64_EA_OLEDS102_4W_HW_SPI u8x8(/* cs=*/ 10, /* dc=*/ 9, /* reset=*/ 8);		// same as the NONAME variant, but may solve the "every 2nd line skipped" problem
//U8X8_SSD1312_128X64_NONAME_4W_SW_SPI u8x8(/* clock=*/ 13, /* data=*/ 11, /* cs=*/ 10, /* dc=*/ 9, /* reset=*/ 8);
//U8X8_SSD1312_128X64_NONAME_SW_I2C u8x8(/* clock=*/ SCL, /* data=*/ SDA, /* reset=*/ 8);
//U8X8_SSD1312_128X64_NONAME_HW_I2C u8x8(/* reset=*/ U8X8_PIN_NONE);
//U8X8_SSD1312_128X32_4W_SW_SPI u8x8(/* clock=*/ 13, /* data=*/ 11, /* cs=*/ 10, /* dc=*/ 9, /* reset=*/ 8);
//U8X8_SSD1312_128X32_SW_I2C u8x8(/* clock=*/ SCL, /* data=*/ SDA, /* reset=*/ 8);
//U8X8_SSD1312_128X32_HW_I2C u8x8(/* reset=*/ U8X8_PIN_NONE);
//U8X8_SSD1312_120X28_4W_SW_SPI u8x8(/* clock=*/ 13, /* data=*/ 11, /* cs=*/ 10, /* dc=*/ 9, /* reset=*/ 8);
//U8X8_SSD1312_120X28_SW_I2C u8x8(/* clock=*/ SCL, /* data=*/ SDA, /* reset=*/ 8);
//U8X8_SSD1312_120X28_HW_I2C u8x8(/* reset=*/ U8X8_PIN_NONE);
//U8X8_SH1106_128X64_NONAME_4W_HW_SPI u8x8(/* cs=*/ 10, /* dc=*/ 9, /* reset=*/ 8);
//U8X8_SH1106_128X64_NONAME_HW_I2C u8x8(/* reset=*/ U8X8_PIN_NONE);
//U8X8_SH1106_128X64_VCOMH0_4W_HW_SPI u8x8(/* cs=*/ 10, /* dc=*/ 9, /* reset=*/ 8);		// same as the NONAME variant, but maximizes setContrast() range
//U8X8_SH1106_128X64_WINSTAR_4W_HW_SPI u8x8(/* cs=*/ 10, /* dc=*/ 9, /* reset=*/ 8);		// same as the NONAME variant, but uses updated SH1106 init sequence
//U8X8_SH1106_128X32_VISIONOX_HW_I2C u8x8(/* reset=*/ U8X8_PIN_NONE); 
//U8X8_SH1106_128X32_VISIONOX_4W_HW_SPI u8x8(/* cs=*/ 10, /* dc=*/ 9, /* reset=*/ 8);
//U8X8_SH1106_72X40_WISE_4W_HW_SPI u8x8(/* cs=*/ 10, /* dc=*/ 9, /* reset=*/ 8);
//U8X8_SH1107_64X128_4W_HW_SPI u8x8(/* cs=*/ 10, /* dc=*/ 9, /* reset=*/ 8);
//U8X8_SH1107_128X128_4W_HW_SPI u8x8(/* cs=*/ 10, /* dc=*/ 9, /* reset=*/ 8);
//U8X8_SH1107_128X128_HW_I2C u8x8(/* reset=*/ 8);
//U8X8_SH1107_128X80_HW_I2C u8x8(/* reset=*/ 8);
//U8X8_SH1107_PIMORONI_128X128_HW_I2C u8x8(/* reset=*/ 8);
//U8X8_SH1107_SEEED_128X128_SW_I2C u8x8(/* clock=*/ SCL, /* data=*/ SDA, /* reset=*/ U8X8_PIN_NONE);
//U8X8_SH1107_SEEED_128X128_HW_I2C u8x8(/* reset=*/ U8X8_PIN_NONE);
//U8X8_SH1107_SEEED_96X96_4W_HW_SPI u8x8(/* cs=*/ 10, /* dc=*/ 9, /* reset=*/ 8);
//U8X8_SH1108_128X160_4W_HW_SPI u8x8(/* cs=*/ 10, /* dc=*/ 9, /* reset=*/ 8);
//U8X8_CH1120_128X160_4W_HW_SPI u8x8(/* cs=*/ 10, /* dc=*/ 9, /* reset=*/ 8);
//U8X8_SH1108_160X160_4W_HW_SPI u8x8(/* cs=*/ 10, /* dc=*/ 9, /* reset=*/ 8);
//U8X8_SSD1306_128X32_UNIVISION_SW_I2C u8x8(/* clock=*/ SCL, /* data=*/ SDA, /* reset=*/ U8X8_PIN_NONE);   // Adafruit Feather ESP8266/32u4 Boards + FeatherWing OLED
//U8X8_SSD1306_128X32_UNIVISION_SW_I2C u8x8(/* clock=*/ 21, /* data=*/ 20, /* reset=*/ U8X8_PIN_NONE);   // Adafruit Feather M0 Basic Proto + FeatherWing OLED
//U8X8_SSD1306_128X32_UNIVISION_HW_I2C u8x8(/* reset=*/ U8X8_PIN_NONE);   // Adafruit ESP8266/32u4/ARM Boards + FeatherWing OLED
//U8X8_SSD1306_128X32_UNIVISION_HW_I2C u8x8(/* reset=*/ U8X8_PIN_NONE, /* clock=*/ SCL, /* data=*/ SDA);   // pin remapping with ESP8266 HW I2C
//U8X8_SSD1306_128X32_WINSTAR_HW_I2C u8x8(/* reset=*/ U8X8_PIN_NONE, /* clock=*/ SCL, /* data=*/ SDA);   // pin remapping with ESP8266 HW I2C
//U8X8_SSD1306_64X48_ER_HW_I2C u8x8(/* reset=*/ U8X8_PIN_NONE);   // EastRising 0.66" OLED breakout board, Uno: A4=SDA, A5=SCL, 5V powered
//U8X8_SSD1306_48X64_WINSTAR_HW_I2C u8x8(/* reset=*/ U8X8_PIN_NONE);
//U8X8_SSD1306_64X32_NONAME_HW_I2C u8x8(/* reset=*/ U8X8_PIN_NONE);  
//U8X8_SSD1306_64X32_1F_HW_I2C u8x8(/* reset=*/ U8X8_PIN_NONE);  
//U8X8_SSD1306_96X16_ER_HW_I2C u8x8(/* reset=*/ U8X8_PIN_NONE);   // EastRising 0.69"
//U8X8_SSD1306_72X40_ER_HW_I2C u8x8(/* reset=*/ U8X8_PIN_NONE);   // EastRising 0.42"
//U8X8_SSD1306_96X40_HW_I2C u8x8(/* reset=*/ U8X8_PIN_NONE);
//U8X8_SSD1306_96X39_HW_I2C u8x8(/* reset=*/ U8X8_PIN_NONE);
//U8X8_SSD1306_128X64_NONAME_6800 u8x8(13, 11, 2, 3, 4, 5, 6, A4, /*enable=*/ 7, /*cs=*/ 10, /*dc=*/ 9, /*reset=*/ 8);
//U8X8_SSD1306_128X64_NONAME_8080 u8x8(13, 11, 2, 3, 4, 5, 6, A4, /*enable=*/ 7, /*cs=*/ 10, /*dc=*/ 9, /*reset=*/ 8);
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
